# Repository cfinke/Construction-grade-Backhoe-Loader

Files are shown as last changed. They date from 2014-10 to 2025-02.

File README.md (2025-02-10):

I converted a set of woodworking plans for a [Construction-grade Backhoe Loader](http://www.woodstore.net/cobalo.html) from WOOD Magazine into a set of 3D-printable models. Files for the parts I printed are available here, along with some instructions on printing them.

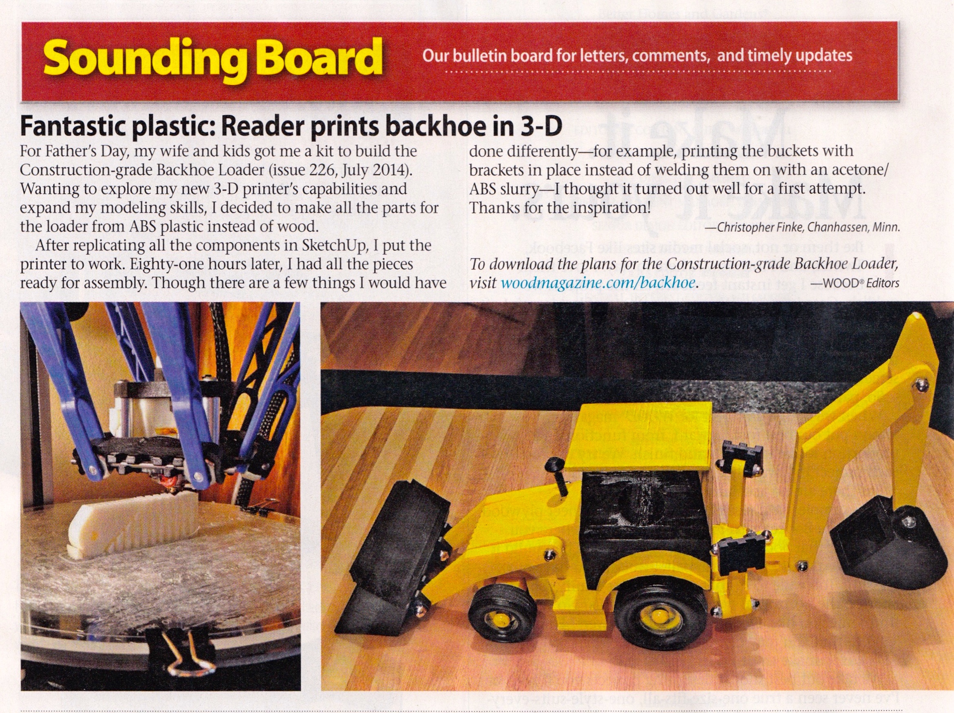
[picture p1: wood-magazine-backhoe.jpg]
A scan of the backhoe when it was published in Wood Magazine.


I printed in ABS and did some post-print gluing and welding with an acetone/ABS slurry.  I did not print the wheels, pegs,  smokestack, or hardware, all of which are available in the [project kit](http://www.woodstore.net/cobalo.html).

These files are published with permission from [WOOD Magazine](http://www.woodmagazine.com/). All original plans for the [Construction-grade Backhoe Loader](http://www.woodstore.net/cobalo.html) are copyright &copy; 2014 Meredith Corporation. If you decide to try and print this project, consider buying the plans and/or the project kit.

Parts
-----
Bracketed superscripted links indicate alternate designs for the pieces, usually to reduce printing time.

| Part | Count | Total Print Time |
|---|---|---|
| [Boom](assets/Boom.stl) | 2 | 13:40 |
| [Bracket](assets/Bracket.stl) | 12 | 0:54 |
| [Bucket Bracket](assets/Bucket%20Bracket.stl) | 2 | 0:09 |
| [Bucket](assets/Bucket.stl) | 1 | 5:06 |
| [Cab](assets/Cab.stl) <sup>[1](assets/Cab%20Bottom.stl "The bottom of the cab, hollow.")</sup> <sup>[2](assets/Cab%20Top.stl "The top of the cab; weld it to the hollow bottom.")</sup> | 1 | 18:57 |
| [Chassis](assets/Chassis.stl) <sup>[1](assets/Chassis%20Back%20Hollow%20Bottom.stl "Save lots of time and plastic by printing the large piece of the chassis in two parts and gluing together.")</sup> <sup>[2](assets/Chassis%20Back%20Hollow%20Top.stl "The 2nd part of the chassis glue-up.")</sup> <sup>[3](assets/Chassis%20Front.stl "The piece of the chassis that is separated by the front axle.")</sup> | 1 | 8:54 |
| [Front Axle](assets/Front%20Axle.stl) | 1 | 1:30 |
| [Hood](assets/Hood.stl) <sup>[1](assets/Hood%20Hollow.stl "Save time and plastic by printing the hood hollow and upside-down.")</sup> | 1 | 6:42 |
| [Loader Arm](assets/Loader%20Arm.stl) | 2 | 9:14 |
| [Loader](assets/Loader.stl) | 1 | 5:19 |
| [Pivot Block](assets/Pivot%20Block.stl) | 1 | 0:35 |
| [Pivot Bracket](assets/Pivot%20Bracket.stl) | 1 | 1:49 |
| [Roof](assets/Roof.stl) | 1 | 2:00 |
| [Stabilizer Foot](assets/Stabilizer%20Foot.stl) | 2 | 0:32 |
| [Stabilizer Leg](assets/Stabilizer%20Leg.stl) | 2 | 0:44 |
| [Step](assets/Step.stl) | 2 | 1:12 |
| [Stick](assets/Stick.stl) | 1 | 3:40 |

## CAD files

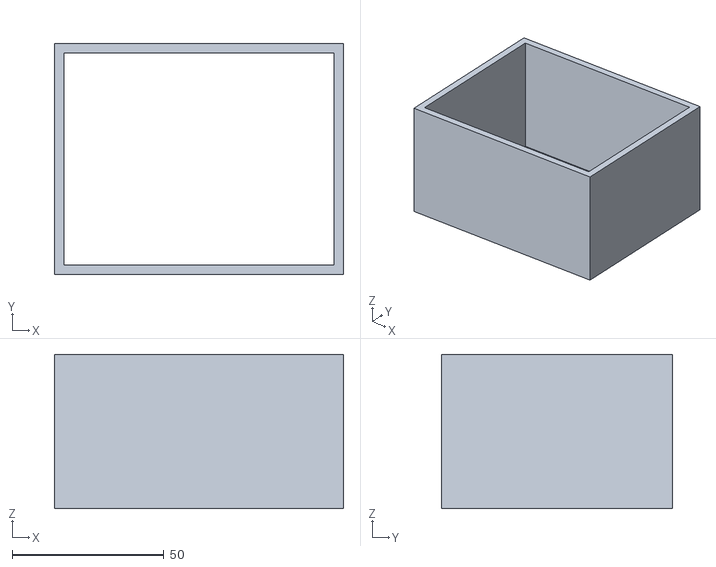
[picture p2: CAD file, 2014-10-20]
assets/Cab Bottom.stl
95.2 x 76.2 x 50.8

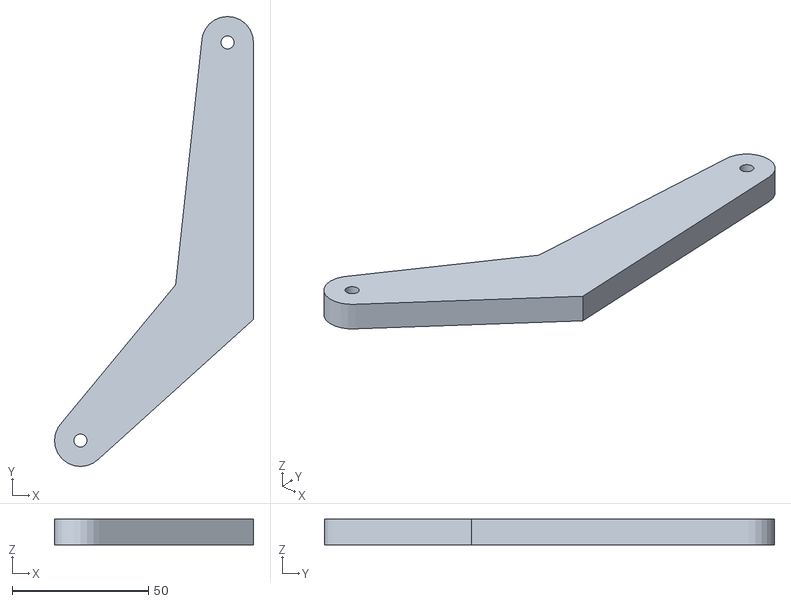
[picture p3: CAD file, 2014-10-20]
assets/Boom.stl
73.0 x 165.1 x 9.52

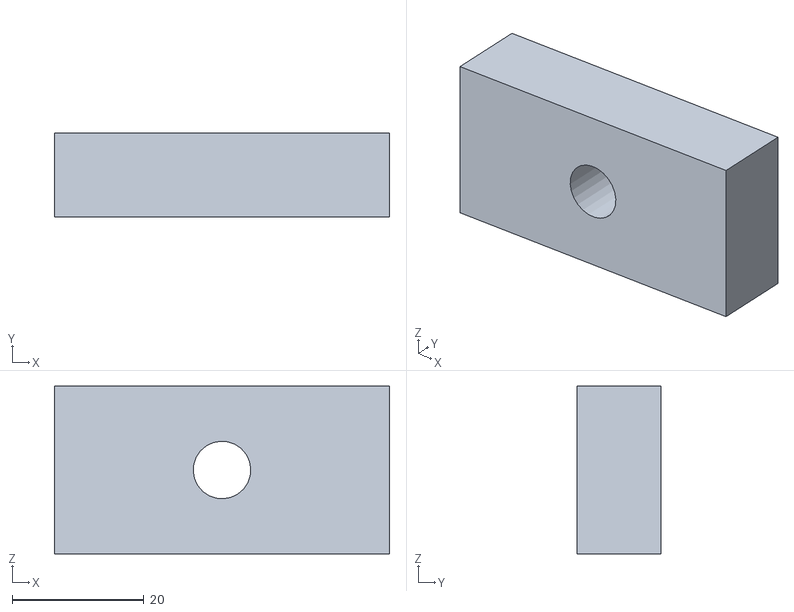
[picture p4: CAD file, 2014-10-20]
assets/Chassis Front.stl
50.8 x 12.7 x 25.4

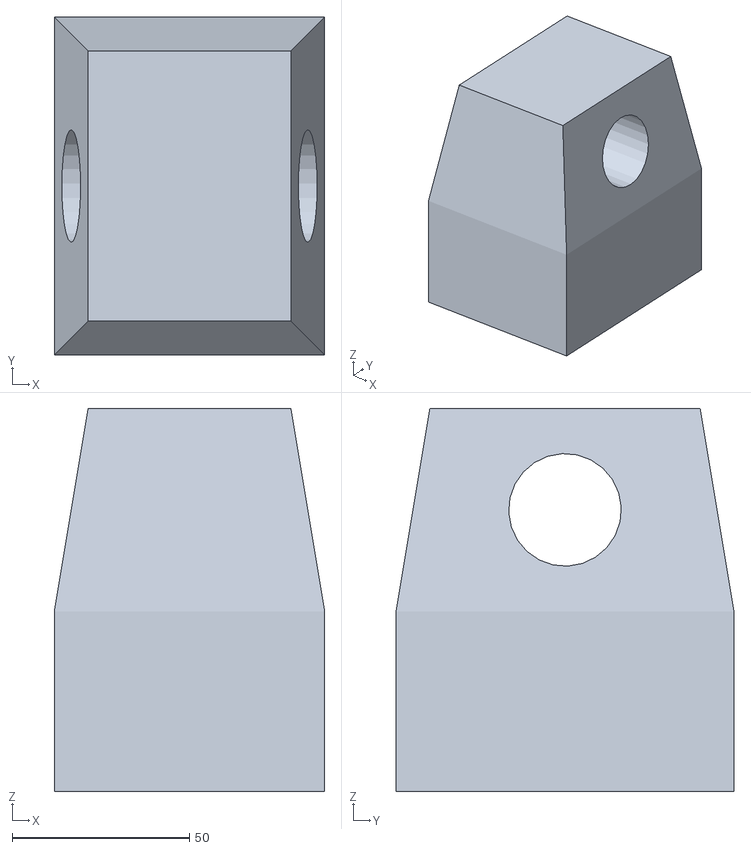
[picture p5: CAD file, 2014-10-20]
assets/Cab.stl
76.2 x 95.2 x 107.9

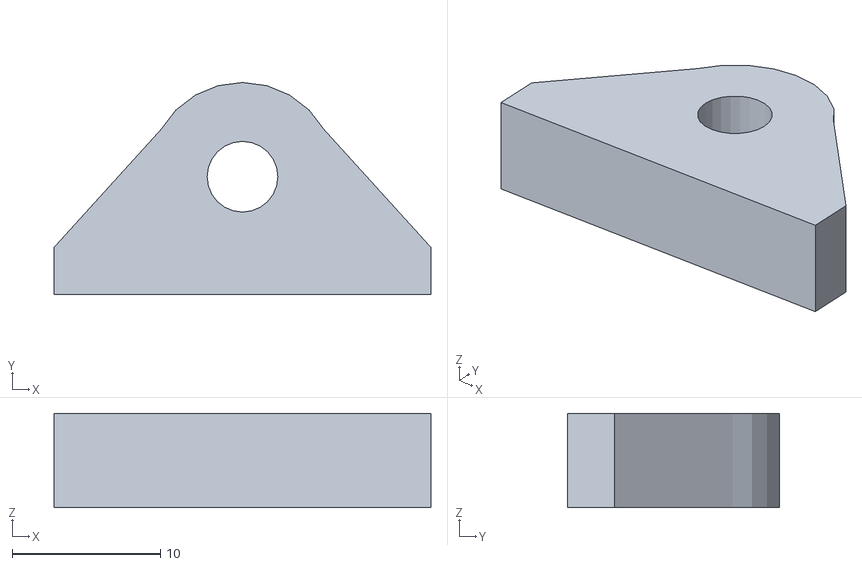
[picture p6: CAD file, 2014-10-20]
assets/Bracket.stl
25.4 x 14.3 x 6.35

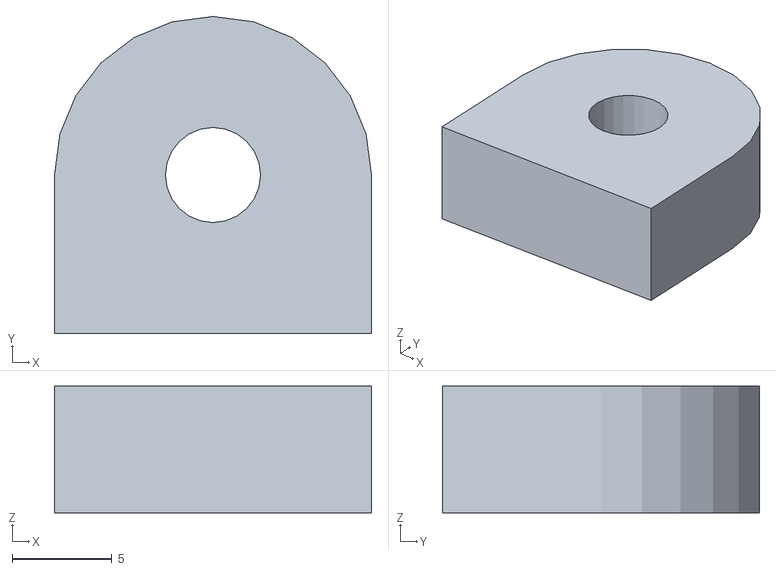
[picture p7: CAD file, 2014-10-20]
assets/Bucket Bracket.stl
15.9 x 15.9 x 6.35

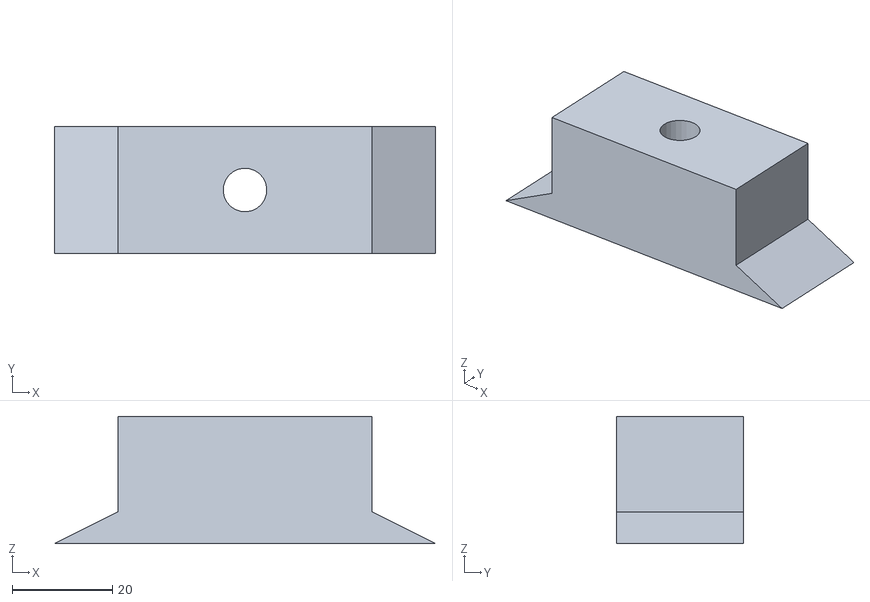
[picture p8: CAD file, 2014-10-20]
assets/Chassis Back Hollow Top.stl
76.2 x 25.4 x 25.4

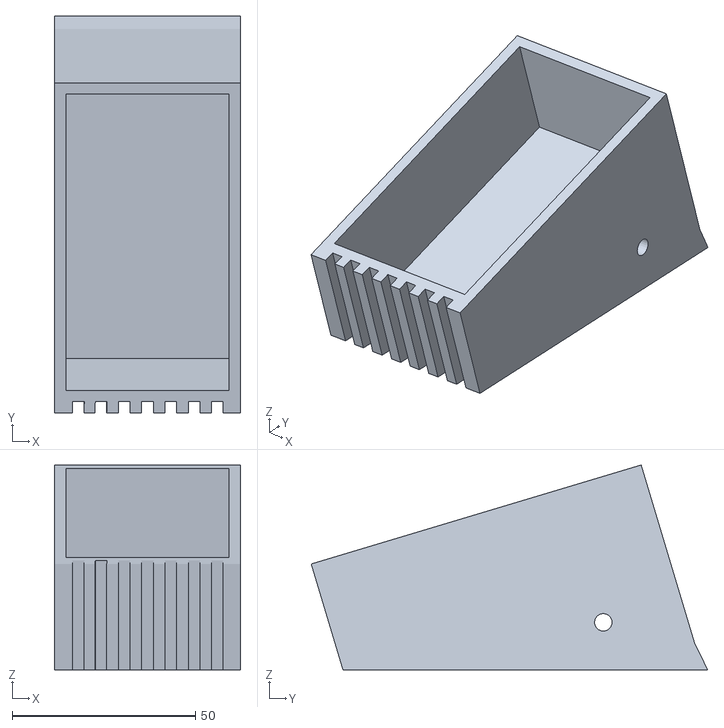
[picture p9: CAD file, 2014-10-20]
assets/Hood Hollow.stl
50.8 x 108.1 x 55.9

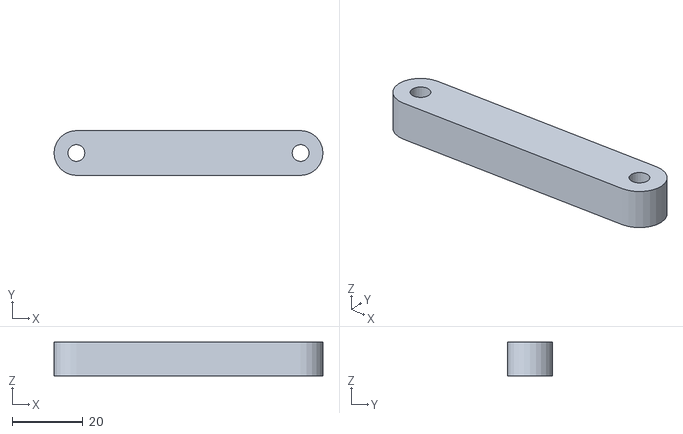
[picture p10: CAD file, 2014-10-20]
assets/Stabilizer Leg.stl
76.2 x 12.7 x 9.52

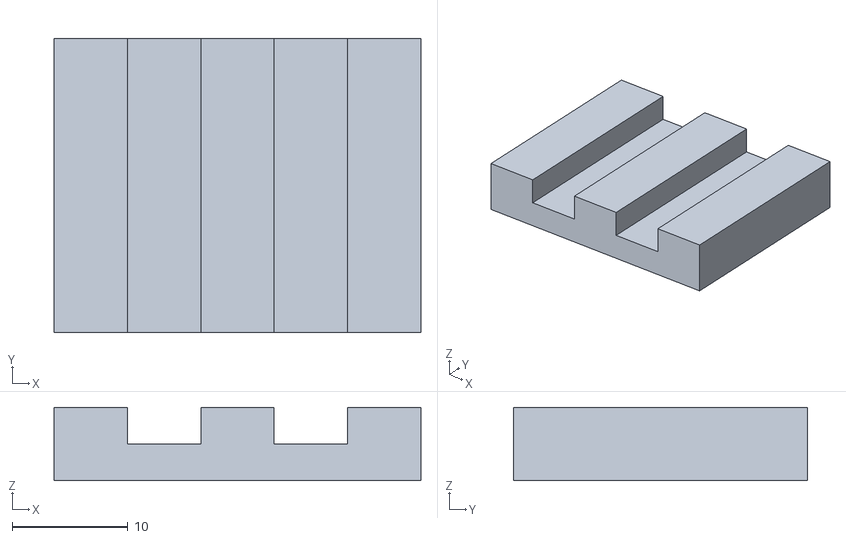
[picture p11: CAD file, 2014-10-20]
assets/Stabilizer Foot.stl
31.7 x 25.4 x 6.35

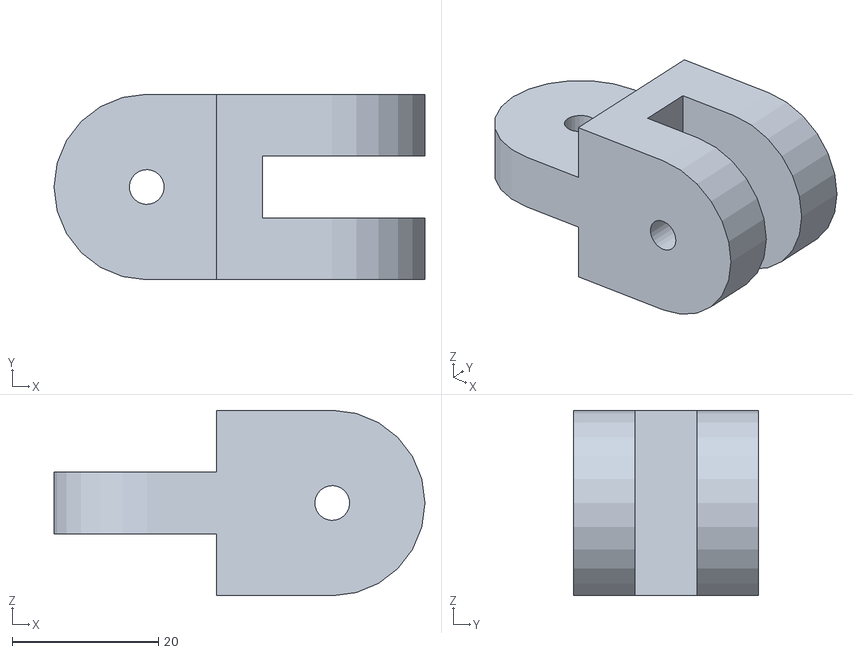
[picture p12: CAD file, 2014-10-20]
assets/Pivot Bracket.stl
50.8 x 25.4 x 25.4

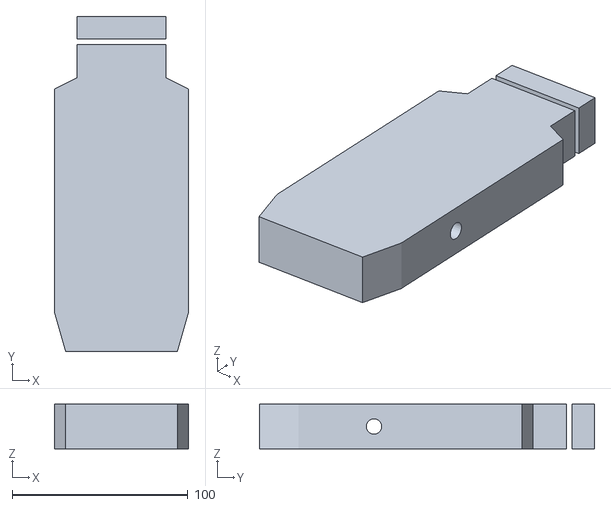
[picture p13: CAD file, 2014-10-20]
assets/Chassis.stl
76.2 x 190.5 x 25.4

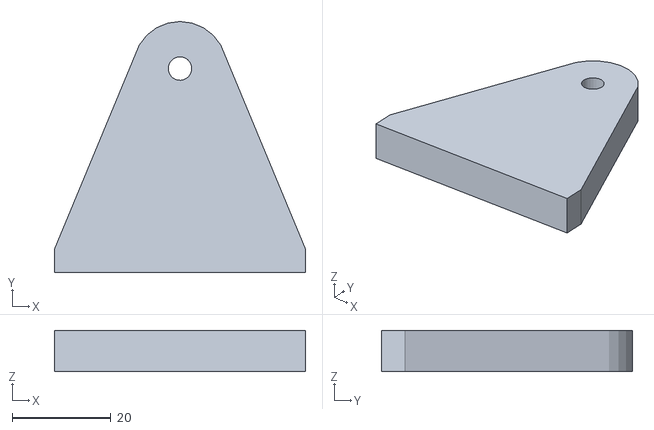
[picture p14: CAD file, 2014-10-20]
assets/Pivot Block.stl
50.8 x 50.8 x 8.33

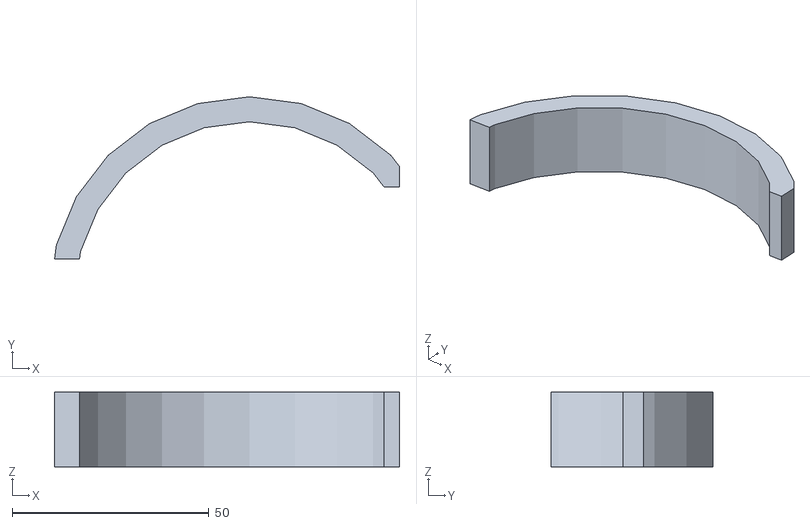
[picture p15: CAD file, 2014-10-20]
assets/Fender.stl
87.6 x 41.3 x 19.0

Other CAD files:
assets/Chassis Back.stl
assets/Bucket.stl
assets/Loader.stl
assets/Loader Arm.stl
assets/Boom.skp
assets/Bracket.skp
assets/Bucket Bracket.skp
assets/Bucket.skp
assets/Cab Bottom.skp
assets/Cab Top.skp
assets/Cab Top.stl
assets/Cab.skp
assets/Chassis Back Hollow Bottom.skp
assets/Chassis Back Hollow Bottom.stl
assets/Chassis Back Hollow Top.skp
assets/Chassis Back.skp
assets/Chassis Front.skp
assets/Chassis.skp
assets/Fender.skp
assets/Front Axle.skp
assets/Front Axle.stl
assets/Hood Hollow.skp
assets/Hood.skp
assets/Hood.stl
assets/Loader Arm.skp
assets/Loader.skp
assets/Pivot Block.skp
assets/Pivot Bracket.skp
assets/Roof.skp
assets/Roof.stl
assets/Stabilizer Foot.skp
assets/Stabilizer Leg.skp
assets/Step.skp
assets/Step.stl
assets/Stick.skp
assets/Stick.stl

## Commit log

2014-10-20 Include links to each printable component along with the print time.
2014-10-20 Adding 3D model files.
    [Boom.skp, Boom.stl, Bracket.skp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]
